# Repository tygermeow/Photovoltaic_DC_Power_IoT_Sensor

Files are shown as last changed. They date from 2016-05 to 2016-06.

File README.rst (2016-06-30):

***********************************************
Photovoltaic DC Smart Energy Meter
***********************************************

Overview
========

The DC Smart Energy Meter is capable of monitoring the power production (i.e. DC current and voltage) from photovoltaics. It used a non-contact hall effect sensor, voltage divider circuit, and a WiFi-SoC to communicate real-time power production to a communication gateway.  This directory is organized into: 

    * Archive
    * Eagle Design Files
    * Enclosure Design Files
    * MC_Firmware 
    * Notes

Description (template)
======================

**Components**
    	1N5822RL Schottky Diode	
    		http://www.digikey.com/product-detail/en/stmicroelectronics/1N5822RL/497-14742-1-ND/4868910
	LM2576 Voltage Regulator
		http://www.digikey.com/product-detail/en/texas-instruments/LM2576SX-3.3-NOPB/LM2576SX-3.3-NOPBCT-ND/3526859
	100 uH Inductor	
		http://www.digikey.com/product-detail/en/bourns-inc/RLB0914-101KL/RLB0914-101KL-ND/2352772
	1000 uF Electrolytic Capacitor SMD
		http://www.mouser.com/ProductDetail/Panasonic/EEE-0JA102UP/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
	100 uF Electrolytic Capacitor SMD
		http://www.mouser.com/ProductDetail/Panasonic/EEE-1HA101UP/?qs=sGAEpiMZZMtZ1n0r9vR22cS6GEbW2fto6jpFqu6vaQU%3d
	47 uF Electrolytic Capacitor SMD
		http://www.mouser.com/ProductDetail/Panasonic/EEE-1CA470WR/?qs=sGAEpiMZZMtZ1n0r9vR22cS6GEbW2ftocdkiN2ijlcU%3d
	Pin Jumpers
		http://www.wholesalecables.com/ProductDetails.asp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
	MCP3208	
		http://www.digikey.com/product-detail/en/microchip-technology/MCP3208T-CI-SL/MCP3208T-CI-SLCT-ND/5818697
	TLV2462 OP AMP	
		http://www.digikey.com/product-detail/en/texas-instruments/TLV2462CDR/296-2434-1-ND/374274
	ESP8266	
		http://www.gearbest.com/transmitters-receivers-module/pp_227650.html?wid=1
	2P Pluggable Term Block	
		http://www.mouser.com/ProductDetail/FCI/20020007-H021B01LF/?qs=sGAEpiMZZMsDddcp1dBDJNR7rNETrFyKff32nDP4Fbc%3d
	2P Pluggable Term Socket
		http://www.mouser.com/ProductDetail/FCI/20020109-H021A01LF/?qs=sGAEpiMZZMsDddcp1dBDJNR7rNETrFyKRqvksFMxIlM%3d
	3P Pluggable Term Block	
		http://www.mouser.com/ProductDetail/FCI/20020007-H031B01LF/?qs=sGAEpiMZZMsDddcp1dBDJNR7rNETrFyKs6VOdOjviT8%3d
	3P Pluggable Term Socket
		http://www.mouser.com/ProductDetail/FCI/20020110-H031A01LF/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
	Some 805 SMD resistors

**Algorithm**
    Voltage is scaled down with a voltage divider and fed into the ADC in input 0.
	Hall effect transducer signal is amplified with the non-inverting op-amp circuit.
	Amplified current signal is input into ADC input 1.
	Calibration data was accumulated to determine appropriate signal processing.
	Data is sampled for 15000 cycles and averaged.
	The average power is output and prepared for sending to database.

	Communication protocol is yet to be determined for sending power data.   

Dependencies (template)
=======================

**Algorithms**
    	#include <ESP8266WiFi.h>
	#include "AH_MCP320x.h"
	#include <SPI.h>
**Eagle**
    	ESP8266-ESP12.lbr
	MCP3208.lbr
	AWJLEagleLib.lbr
	Texas Instruments_By_element14_Batch_1.lbr

**Hardware**
    	The plate file in the EAGLE folder contains the brd for laser cutting.
	The design is for two plates to sandwich the hall effect transducer with the PCB sitting on top of the assembly. 
	The entire assembly is designed to fit into a marine grade PVC single gang electrical enclosure.
	Maximum input voltage is 40VDC and is regulated down to 3.3VDC.
	This is designed with the open circuit voltage of a single panel or panels in parallel in mind.

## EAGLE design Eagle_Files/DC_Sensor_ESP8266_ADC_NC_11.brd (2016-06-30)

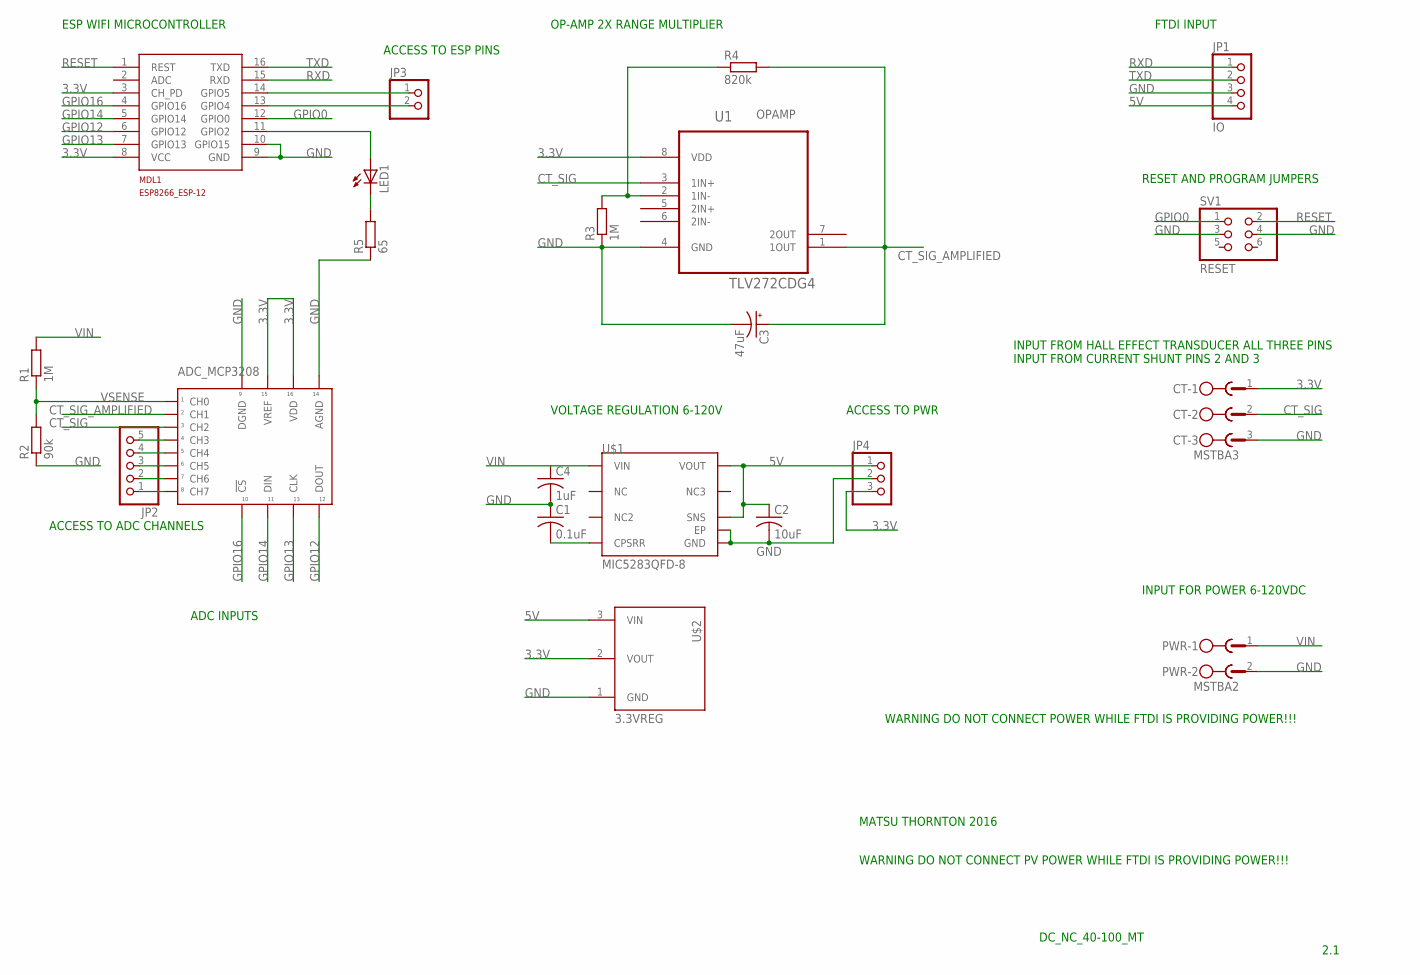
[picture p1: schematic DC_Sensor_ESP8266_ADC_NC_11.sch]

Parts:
ADC_MCP3208: 21298ESMD; PDIP16
C1: 0.1uF; C0402; MFG# GRM155R71C104KA88J
C2: 10uF; C0603K
C3: 47uF; PANASONIC_C
C4: 1uF; C2220K; MFG# C5750X7R2E105M230KA
CT: MSTBA3
JP1: IO; 1X04
JP2: PINHD-1X5; 1X05
JP3: PINHD-1X2; 1X02
JP4: PINHD-1X3; 1X03
LED1: LEDCHIP-LED0603; CHIP-LED0603
MDL1: ESP8266-12GPIO04/05_CORRECTED; ESP8266-ESP12
PWR: MSTBA2
R1, R3: 1M; R0805
R2: 90k; R0805
R4: 820k; R0805
R5: 65; R0805
SV1: RESET; 2X03
U1: TLV272CDG4; SOIC127P600X175-8N
U$1: MIC5283QFD-8; 8-VDFN
U$2: 3.3VREG; 3PVREG

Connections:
3.3V: ADC_MCP3208.P$15 (VREF), ADC_MCP3208.P$16 (VDD), CT.1, JP4.3, MDL1.3 (CH_PD), MDL1.8 (VCC), U1.8 (VDD), U$2.2 (VOUT)
5V: C2.1, JP1.4, JP4.1, U$1.P$6 (SNS), U$1.P$8 (VOUT), U$2.3 (VIN)
CT_SIG: ADC_MCP3208.P$3 (CH2), CT.2, U1.3 (1IN+)
CT_SIG_AMPLIFIED: ADC_MCP3208.P$2 (CH1), C3.+, R4.2, U1.1 (1OUT)
GND: ADC_MCP3208.P$9 (DGND), ADC_MCP3208.P$14 (AGND), C1.1, C2.2, C3.-, C4.2, CT.3, JP1.3, JP4.2, MDL1.9 (GND), MDL1.10 (GPIO15), PWR.2, R2.1, R3.1, R5.1, SV1.3, SV1.4, U1.4 (GND), U$1.EXP (EP), U$1.P$5 (GND), U$2.1 (GND)
GPIO0: MDL1.12 (GPIO0), SV1.1
GPIO12: ADC_MCP3208.P$12 (DOUT), MDL1.6 (GPIO12)
GPIO13: ADC_MCP3208.P$13 (CLK), MDL1.7 (GPIO13)
GPIO14: ADC_MCP3208.P$11 (DIN), MDL1.5 (GPIO14)
GPIO16: ADC_MCP3208.P$10 (!CS), MDL1.4 (GPIO16)
unnamed: LED1.A, MDL1.11 (GPIO2)
unnamed: R3.2, R4.1, U1.2 (1IN-)
unnamed: LED1.C, R5.2
unnamed: C1.2, U$1.P$4 (CPSRR)
unnamed: JP3.1, MDL1.14 (GPIO5)
unnamed: JP3.2, MDL1.13 (GPIO4)
unnamed: ADC_MCP3208.P$4 (CH3), JP2.5
unnamed: ADC_MCP3208.P$5 (CH4), JP2.4
unnamed: ADC_MCP3208.P$6 (CH5), JP2.3
unnamed: ADC_MCP3208.P$7 (CH6), JP2.2
unnamed: ADC_MCP3208.P$8 (CH7), JP2.1
RESET: MDL1.1 (REST), SV1.2
RXD: JP1.1, MDL1.15 (RXD)
TXD: JP1.2, MDL1.16 (TXD)
VIN: C4.1, PWR.1, R1.2, U$1.P$1 (VIN)
VSENSE: ADC_MCP3208.P$1 (CH0), R1.1, R2.2

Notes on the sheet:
DC_NC_40-100_MT
2.1
MATSU THORNTON 2016
VOLTAGE REGULATION 6-120V
OP-AMP 2X RANGE MULTIPLIER
FTDI INPUT
RESET AND PROGRAM JUMPERS
INPUT FROM HALL EFFECT TRANSDUCER ALL THREE PINS INPUT FROM CURRENT SHUNT PINS 2 AND 3
INPUT FOR POWER 6-120VDC
WARNING DO NOT CONNECT PV POWER WHILE FTDI IS PROVIDING POWER!!!
WARNING DO NOT CONNECT POWER WHILE FTDI IS PROVIDING POWER!!!
ESP WIFI MICROCONTROLLER
ADC INPUTS
ACCESS TO ESP PINS
ACCESS TO ADC CHANNELS
ACCESS TO PWR

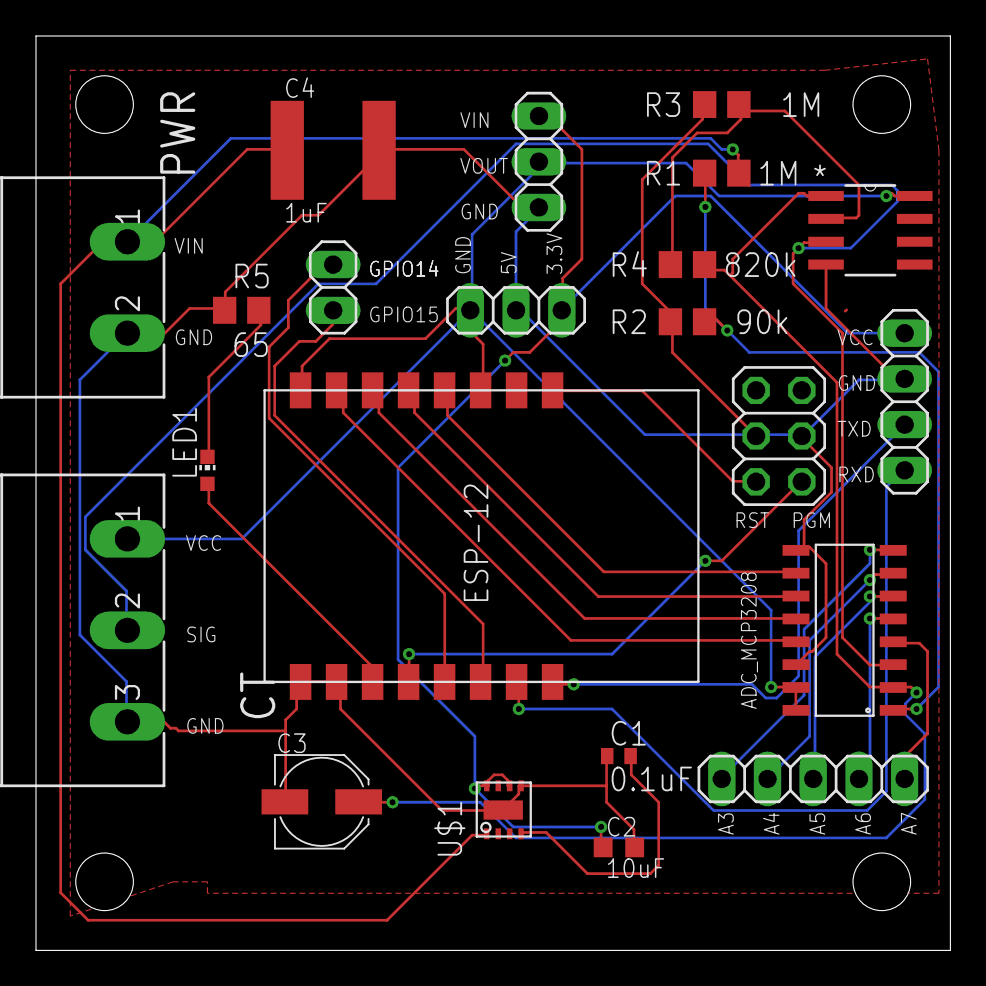
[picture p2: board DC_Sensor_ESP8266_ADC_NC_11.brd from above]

Board: 2 copper layers, 50.8 x 50.8 mm, 22 parts (0 on the bottom side), 26 nets.

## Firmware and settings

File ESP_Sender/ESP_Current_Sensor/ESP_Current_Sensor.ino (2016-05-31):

/* This code is an alternative method for capturing DC power from
 *  PV panels.  There is a 328P which will capture the DC voltage and
 *  send values via I2C.  This device will capture the DC current through
 *  hall effect transducer via the ADC pin.  The transducer has an offset
 *  of 2.34V and I was having trouble with the op amp that we had available
 *  so alternatively I can just voltage divide between 2.34 and 0V for the 
 *  current range to get the full 10 bit resolution between 0 and 1 V.This is
 *  a voltage divider with a 1M and 746k resistor.
 */
#define DEBUG 1
#include <ESP8266WiFi.h>
#include <ESP8266WiFiAP.h>
#include <ESP8266WiFiGeneric.h>
#include <ESP8266WiFiMulti.h>
#include <ESP8266WiFiScan.h>
#include <ESP8266WiFiSTA.h>
#include <ESP8266WiFiType.h>
#include <WiFiClient.h>
#include <WiFiClientSecure.h>
#include <WiFiServer.h>
#include <WiFiUdp.h>
#include <Wire.h>

double current = 0;  //storage space for reading current through ADC
int   voltage = 0;  //voltage will come in through I2C
double power = 0;   //likewise for power

void setup() {
if(DEBUG) Serial.begin(9600);
Wire.begin();     //setup default pins 2 (SDL) 14 (SDA)
}

void loop() {

  //********************POWER ACQUISITION**************************
  int incoming_voltage[2];
  current = analogRead(A0);                 //read the current signal off of the ADC pin
  current = map(current, 0, 1023, 30, 0);  //I'll replace this later with a calibrated curve

  Wire.requestFrom(5,2);    //request the 2 bytes of data off of the ADC from 328P partner MC
  if(Wire.available()==2) 
  {
    for(int i=0; i<3; i++) incoming_voltage[i]=Wire.read();
    voltage = (incoming_voltage[0]<<8) + incoming_voltage[1];
    voltage = map(voltage, 0, 1023, 0, 40000);      //set voltage in millivolts
    if(DEBUG) Serial.println(voltage);
  }
  power = current*voltage/1000;     //calculate power
  if(DEBUG) Serial.println(power);
  //*****************************************************************
}

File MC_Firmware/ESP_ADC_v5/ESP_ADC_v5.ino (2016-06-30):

/*	DC Energy Meter
 *	
 *	By: Matsu Thornton
 *	Updated: 06/25/2016
 * 
 *	DC energy meter for photovoltaic installations using DC hall-effect sensor.
 *
 */

/*		libraries					*/
#include <ESP8266WiFi.h>
#include "AH_MCP320x.h"
#include <SPI.h>

/*		debugging					*/
#define SER_DEBUG 1             

/*	    WiFi network to join		*/
const char* ssid = "WRTnode_Proto";
const char* password = "12345678";
const char* host="192.168.8.1";
const int httpPort = 9000;

/* create an instance of the client	*/
WiFiClient client;

/*		DRMS definition				*/
int plug = 8;

/*		constants					*/ 
int led = 2;

/*		variables					*/
//int voltage = 0;
//int accumulate_voltage;
//double current = 0;
//double accumulate_current;
//int power = 0;
//int i = 0;
//double accumulate_power = 0;

/*		MCP308 ADC					*/
// AH_MCP320z(int CS_pin, int DOUT_pin, int DIN_pin, int CLK_pin)
AH_MCP320x ADC_pin(16, 14, 12, 13); 

void setup() {
  
  if (SER_DEBUG) Serial.begin(9600);
  
  pinMode(led, OUTPUT);
  digitalWrite(led, LOW);  
  WiFi.begin(ssid, password);
  
  while (WiFi.status() != WL_CONNECTED) {
    delay(500);
    if (SER_DEBUG) Serial.print(".");
  }
  if (SER_DEBUG){
  Serial.println("");
  Serial.println("WiFi connected");
  }
  
  //server.begin();                              // Start the server
  //digitalWrite(led, HIGH);
  //if (SER_DEBUG) {
  //  Serial.println("Server started");           // info message
  //  Serial.println(WiFi.localIP());             // Print the IP address
  //}
}


void loop() {

  int powerValue = calculatePower();

  sendData(powerValue);

}

int calculatePower(){
  digitalWrite(led, LOW);
  /*	1 second of data acquisition	*/ 
	int iter = 0;
	float accumulate_voltage = 0;
	float accumulate_current = 0;
	float accumulate_power = 0;	
	while (iter < 15000) {
		/*	Get Voltage				*/ 
		float voltage = ADC_pin.readCH(0) * 0.0170969993021633*100-26.78;	// read pin and convert to something
		accumulate_voltage = accumulate_voltage + voltage;		//voltage divider for input is 1M and 90k
		delayMicroseconds(15);

		/*	Get Current				*/
		int current = -0.078974358974359*ADC_pin.readCH(1)+ 161.34;                //ok calibrated
		accumulate_current = accumulate_current + current;
		
		/*	Calculate accumulate power	*/
		accumulate_power = accumulate_power + voltage*current;

		/*	Update iterations						*/ 
		iter++;
  }

	/* 	Signal that data acquisition finished 	*/  
	digitalWrite(led, HIGH);
	
	/* 	calculate power and convert to int			*/
	int avg_power = int (accumulate_power/(iter*100.0) * 100.0);
  if (avg_power < 1000) avg_power = 0;
	
	/* 	print debugs									*/	
	if (SER_DEBUG) {
      Serial.println(accumulate_power);
      Serial.print("ding");
      Serial.println("----------");
      Serial.println(avg_power);
      Serial.print("voltage: ");
      Serial.println(accumulate_voltage/iter);
      Serial.print("current: ");
      Serial.println(accumulate_current/iter);
  }
  
	/* return average power 		*/
	return avg_power;
}

void sendData(int value){

	/* try connecting to hose 	*/ 
  if (!client.connect(host, httpPort)) {
      if (SER_DEBUG) Serial.println("connection failed");
      return;
  }

	/* if connect, send string to WRTnode */ 
  else {
    String url = "/Type?";
		url += String(plug);
    url += "/Current?";
    url += String(value);
    url += "/State?";
    url += String(1);
  
    client.print(String("GET "+url+" HTTP/1.1\r\n"+
                "Host: "+host+" \r\n"+
                "Connection: close\r\n\r\n"));
    delay(50);
    
  }
 
 	client.flush();
  
}

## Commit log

2016-05-05 Start of DC Sensor Code
2016-05-05 Rename DC_Sensor.ino to DC_Sensor_v1.2.ino
    No 1 second for loop, getting ready to change over to variable time requests from master unit and report average power over whatever period happens between requests.
2016-05-05 Added files via upload
    Original with one second interval for for loop collecting sample data
2016-05-05 Placed Slave Sensor files into the ATmega328_SensorInput folder. This is the slave sender under I2C
2016-05-05 This update gives the average power for the sample period between requests from the wifi master sender. The time period sampled over is not necessarily uniform but is an average for that period which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
2016-05-07 ESP8266 sister board sender files added.
    Prototype is still non-functional
2016-05-31 DC sensor based on a non-contact hall effect sensor. Will regulate from 0-40VDC. Update of files includes a link to onenote development documentation. Also includes outline template of baseplate for 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
    [DC_Sensor_ESP8266_ADC_NC_01_PLATE.brd, DC_Sensor_ESP8266_ADC_NC_02.brd, DC_Sensor_ESP8266_ADC_NC_02.sch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]
2016-06-30 Updated to latest 11b ribbon board
    [DC_Sensor_ESP8266_ADC_NC_03.brd, DC_Sensor_ESP8266_ADC_NC_03.sch, DC_Sensor_ESP8266_ADC_NC_08.brd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]
